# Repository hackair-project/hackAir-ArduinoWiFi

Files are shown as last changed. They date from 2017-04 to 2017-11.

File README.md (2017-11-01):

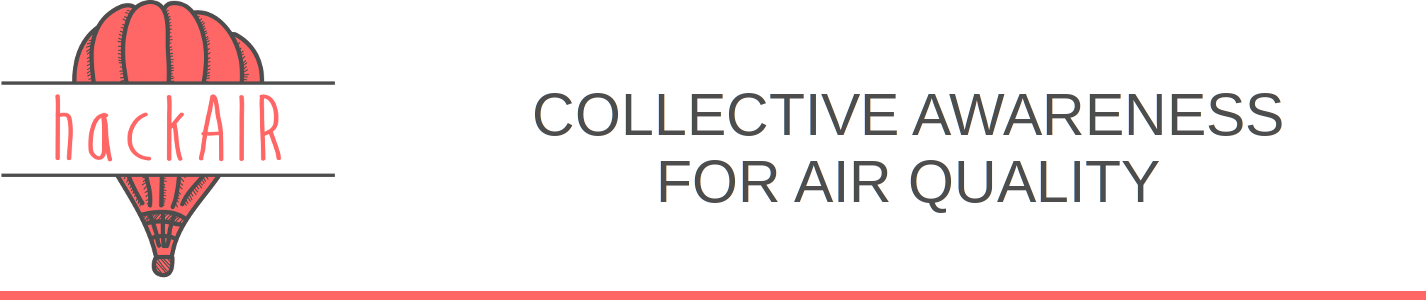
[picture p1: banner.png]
hackAIR banner with logo


hackAIR is an EU-funded project aiming to develop an open technology platform for citizen observatories on air quality. Air pollution is an environmental issue with serious health and lifespan implications. However, it remains difficult for citizens to assess their exposure to air pollution and air quality issues in their country. Official air quality sensors are often few and far between, coverage is poor outside cities, and their data is not always easily accessible.

## hackAIR WiFi shield

The hackAIR WiFi shield is a do-it-yourself solution for adding wireless connectivity to an Arduino node on the cheap. It's based around a custom PCB and the ESP8266 WiFi module and it's supported by the hackAIR firmware. All the network-related work is done by the WiFi module that can be controlled by simple serial commands. The [hackAIR library for Arduino](https://github.com/hackair-project/hackAir-Arduino) contains helpful wrapper functions to make using the shield easy and simple.

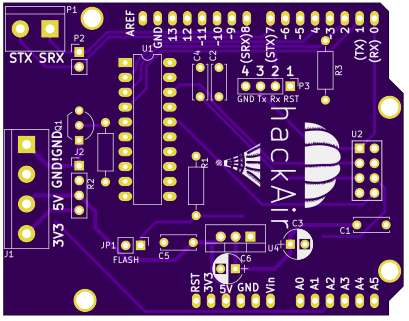
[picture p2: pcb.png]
PCB render


### Where to order

PCBs can be ordered directly from OSHPark [here](https://oshpark.com/shared_projects/u7Z6d8GR). The source files are included in this repository so anyone can order from their manufacturer of choice. Work is being done  to make complete kits available soon.

### Documentation

Documentation for this shield is under construction [here](https://hackair-project.github.io/hackAir-Arduino/wifi/).

### Technicalities

The PCB is designed using the open source EDA called [KiCad](http://kicad-pcb.org/). The PCB render shown above is created using [PcbDraw](https://github.com/yaqwsx/PcbDraw).

### Changelog

#### Version 2.2

* Fix silkscreen of transistor Q1
* Remove footprint for ESP-12
* Add silkscreen for the programming header (pin numbers and names)

#### Version 2
 - [Add] Pull-down resistor for pin 2 (ESP Reset) so the user can flash the Arduino without jumpers
 - [Add] Silkscreen markings for pin numbers
 - [Add] Programming header for the WiFi module
 - [Del] Removed sensor I/O header used by analog sensors
 - [Del] Removed the RC filter required by some analog sensors by SHARP
 - [Fix] Move some decoupling capacitors closer to the power pads
 - [Fix] Moved the CONN_POWER and CONN_SERIAL connectors away from the USB connector of the Arduino board
 - [Fix] Fixed some acid traps in the routing
 - [Fix] Fixed the footprint of Q1 (DSG -> DGS)
 - [Fix] Changed the foorprints of all non-electrolytic caps to be wider.
 - [Fix] Fixed the silkscreen of U1 appearing on the wrong layer.

#### Version 1
Initial release

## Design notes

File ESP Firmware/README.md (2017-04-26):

# ESP Firmware for the Arduino WiFi Shield
This directory houses the ESP firmware's source code along with the configuration landing page.

## Description & Features
The ESP microcontroller is responsible for the following things when using the hackAIR Arduino WiFi shield:

* Manage network connections
* Store AP keys
* Send data received from the Arduino to the hackAIR servers
* Handle WiFi configuration

To handle the WiFi pairing we are using nodemcu's internal 'End-User setup'. The end result can be achieved with
very little code and the page is customizable.

When it's powered on, the ESP checks if there are any known WiFi Access Points in range to connect. If nothing is
available, the ESP will start broadcasting it's own SSID and accept connections from other devices. The user can use
their phone to select a WiFi network for the Arduino to use and input it's password. When instructed by the Arduino, the
ESP will use this WiFi network to transmit gathered data.
 
List of features:
* Full featured HTTP server in AP mode.
* Easy-to-use landing page for configuring WiFi connections
* Handle all network stack duties, leaving the Arduino free to interface with external devices.
* Power saving mode for extending battery life (WIP)

## Install/Use
For users looking to install the firmware to their devices there are tutorials and pre-built images available.
For developers looking to modify the firmware, the development stack is based on Node.JS and the node package manager
(npm). From a terminal at this directory type:

    npm install
    
All required packages for developing will be installed. nodemcu-tool is used to manage writing files to the module.
A couple of npm scripts are available to aid in development:
 * `npm run upload`: Upload everything to the ESP module.
 * `npm run format`: Format the ESP's filesystem.
 * `npm run terminal`: Open a terminal to the ESP module.
 * `npm run build-image`: This will create a `app.bin` file that you can flash using `esptool.py`. This is useful when
 you want to flash both nodemcu and the init.lua in one step. 
 
If uploading is unstable you can try lowering the baud rate at `.nodemcutool`. 9600 is usually a safe bet but it's really slow.
 
## License

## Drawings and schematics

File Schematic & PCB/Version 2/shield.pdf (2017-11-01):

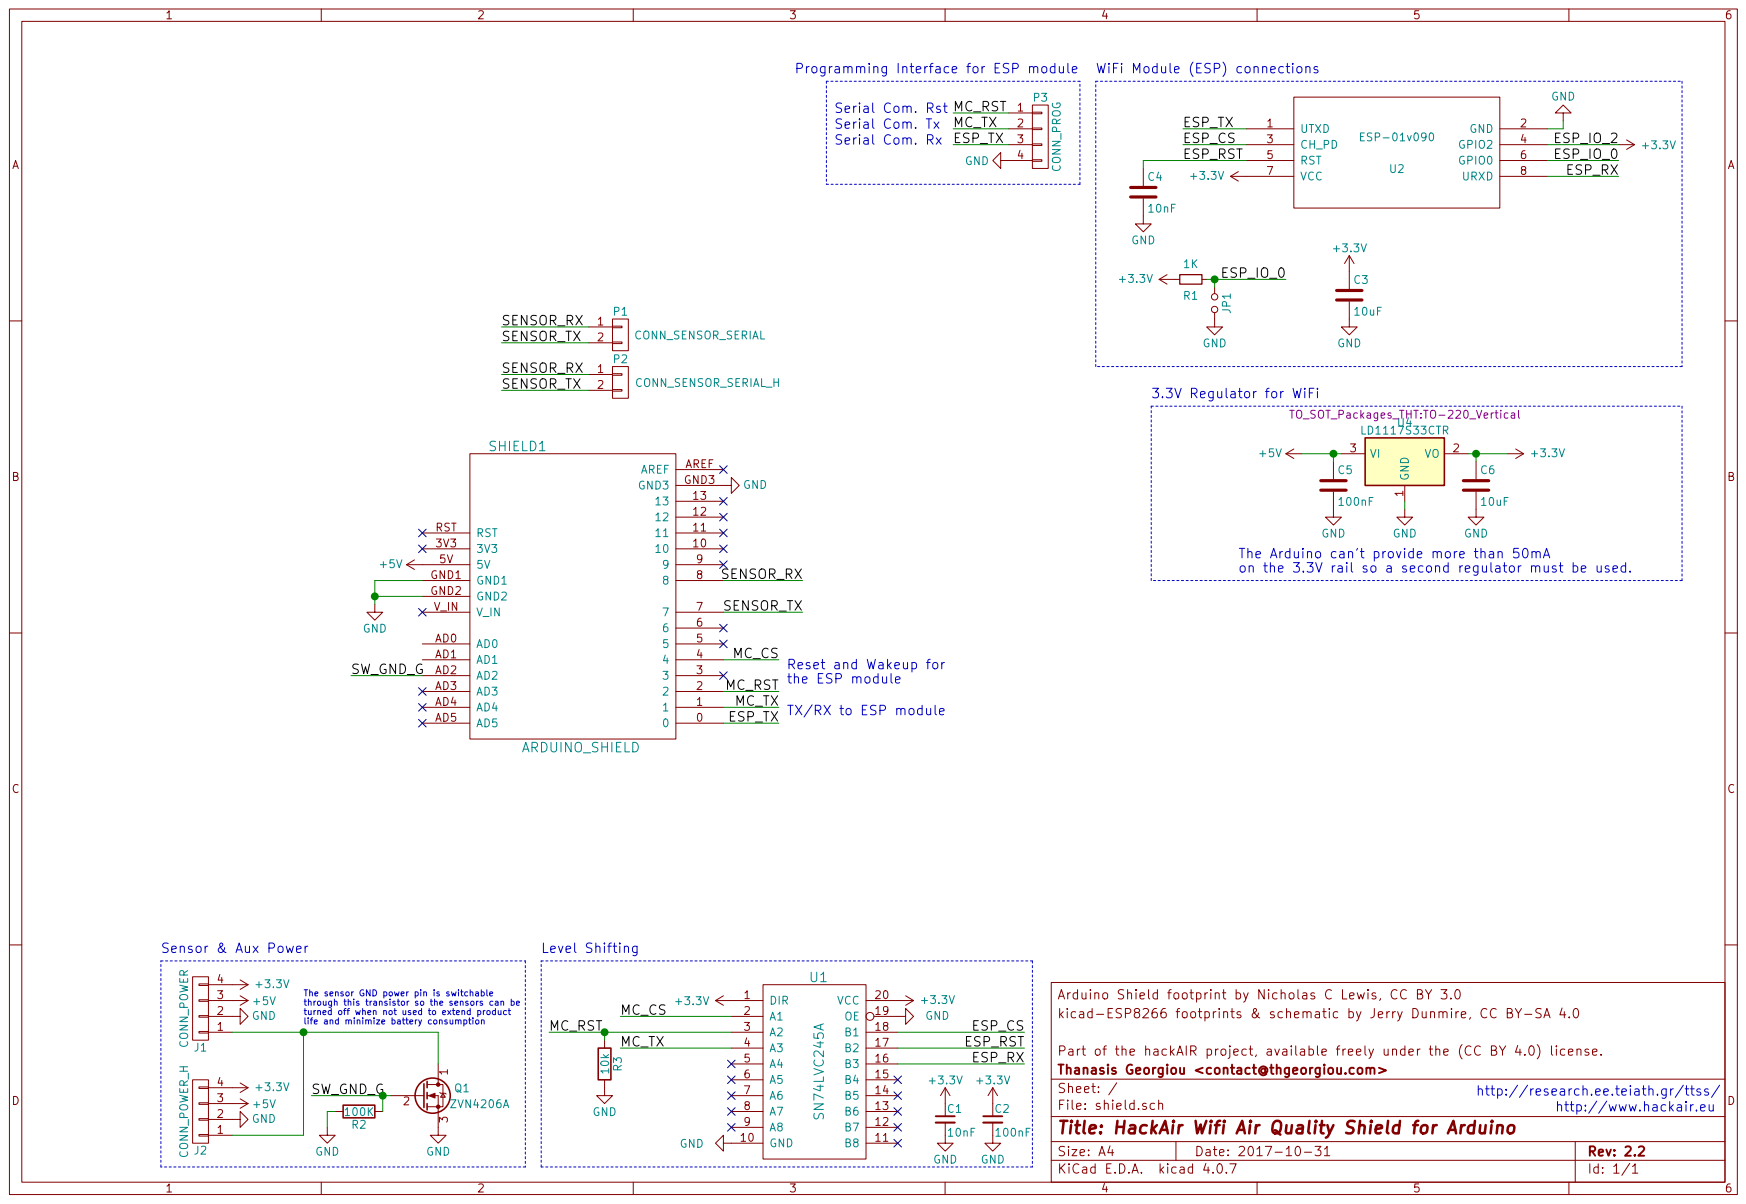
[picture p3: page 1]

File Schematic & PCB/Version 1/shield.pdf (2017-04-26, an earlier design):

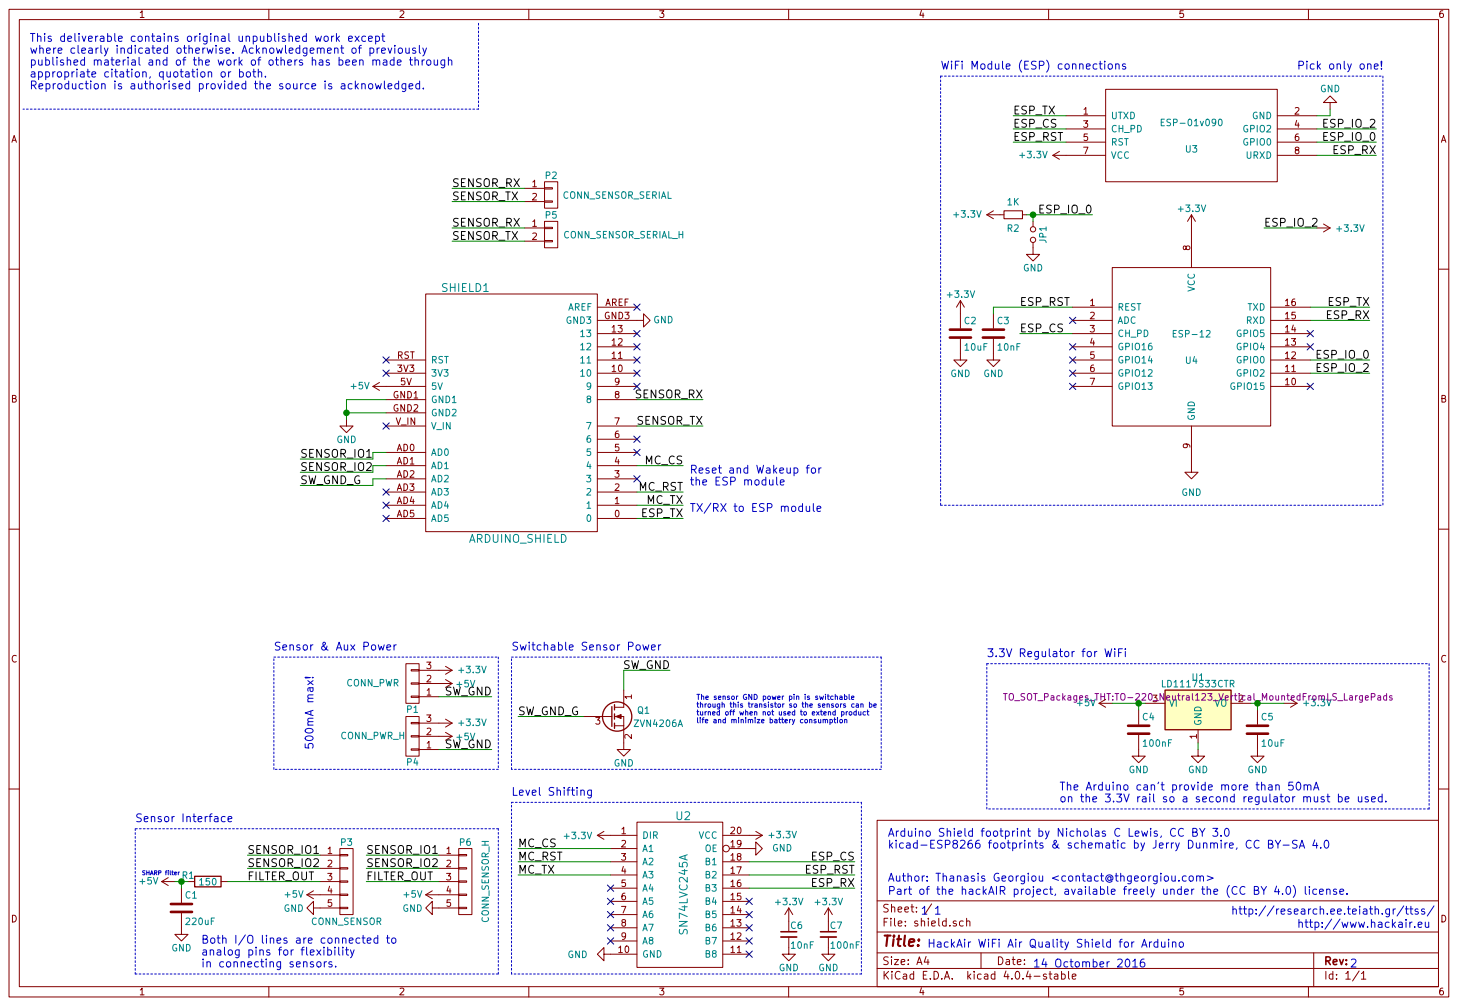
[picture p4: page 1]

where clearly indicated otherwise. Acknowledgement of previously
published material and of the work of others has been made through
appropriate citation, quotation or both.
Reproduction is authorised provided the source is acknowledged.

MC_CS Reset and Wakeup for

The sensor GND power pin is switchable
through this transistor so the sensors can be
turned off when not used to extend product

+5V The Arduino can't provide more than 50mA

kicad-ESP8266 footprints & schematic by Jerry Dunmire, CC BY-SA 4.0 1

Author: Thanasis Georgiou <contact@thgeorgiou.com>
Part of the hackAIR project, available freely under the (CC BY 4.0) license.
Id: 1/1 Title: File: shield.sch Sheet: /

220uF GND
Both I/O lines are connected to
analog pins for flexibility
in connecting sensors.

http://research.ee.teiath.gr/ttss/

http://www.hackair.eu

HackAir WiFi Air Quality Shield for Arduino

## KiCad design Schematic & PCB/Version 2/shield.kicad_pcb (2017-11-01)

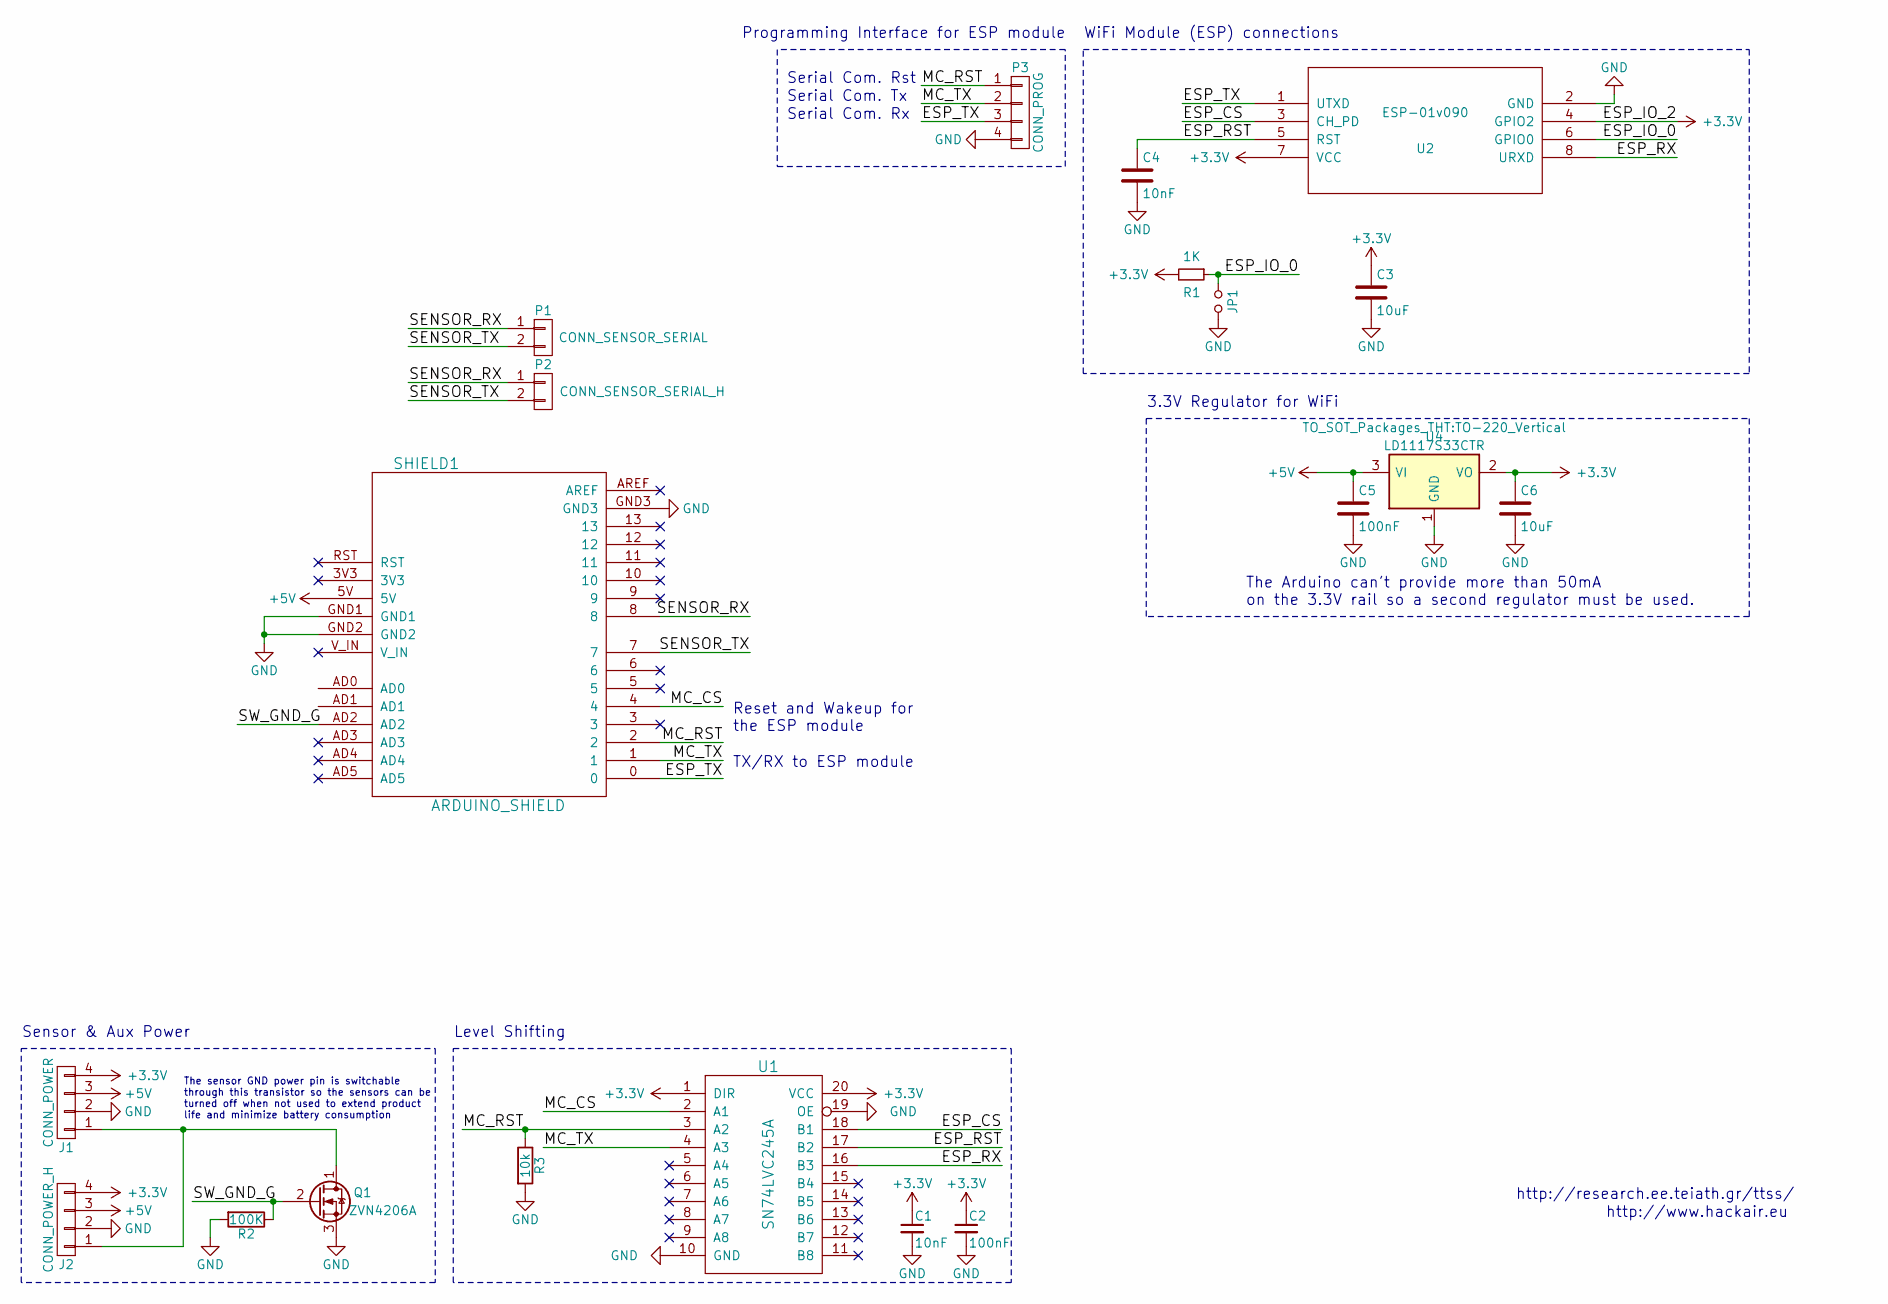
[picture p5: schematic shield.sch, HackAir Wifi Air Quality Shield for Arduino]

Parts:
C1, C4: 10nF; C_Disc_D6.0mm_W2.5mm_P5.00mm
C2, C5: 100nF; C_Disc_D6.0mm_W2.5mm_P5.00mm
C3, C6: 10uF; CP_Radial_D5.0mm_P2.50mm
J1: CONN_POWER; bornier4
J2: CONN_POWER_H; Pin_Header_Straight_1x04_Pitch2.54mm
JP1: Jumper_NO_Small; Pin_Header_Straight_1x02_Pitch2.54mm
P1: CONN_SENSOR_SERIAL; bornier2
P2: CONN_SENSOR_SERIAL_H; Pin_Header_Straight_1x02_Pitch2.54mm
P3: CONN_PROG; Pin_Header_Straight_1x04_Pitch2.54mm
Q1: ZVN4206A; TO-92_Inline_Wide
R1: 1K; R_Axial_DIN0207_L6.3mm_D2.5mm_P10.16mm_Horizontal
R2: 100K; R_Axial_DIN0207_L6.3mm_D2.5mm_P10.16mm_Horizontal
R3: 10k; R_Axial_DIN0207_L6.3mm_D2.5mm_P10.16mm_Horizontal
SHIELD1: ARDUINO_SHIELD; ARDUINO_SHIELD_2_040pins
U1: SN74LVC245A; DIP-20_W7.62mm_LongPads
U2: ESP-01v090; ESP-01
U4: LD1117S33CTR; TO-220_Vertical

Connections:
+3V3: C1.1, C2.1, C3.1, C6.1, J1.4, J2.4, R1.2, U1.1 (DIR), U1.20 (VCC), U2.4 (GPIO2), U2.7 (VCC), U4.2 (VO)
+5V: C5.1, J1.3, J2.3, SHIELD1.5V, U4.3 (VI)
/ESP_CS: U1.18 (B1), U2.3 (CH_PD)
/ESP_IO_0: JP1.1, R1.1, U2.6 (GPIO0)
/ESP_RST: C4.1, U1.17 (B2), U2.5 (RST)
/ESP_RX: U1.16 (B3), U2.8 (URXD)
/ESP_TX: P3.3, SHIELD1.0, U2.1 (UTXD)
/MC_CS: SHIELD1.4, U1.2 (A1)
/MC_RST: P3.1, R3.1, SHIELD1.2, U1.3 (A2)
/MC_TX: P3.2, SHIELD1.1, U1.4 (A3)
/SENSOR_RX: P1.1, P2.1, SHIELD1.8
/SENSOR_TX: P1.2, P2.2, SHIELD1.7
/SW_GND_G: Q1.2 (G), R2.1, SHIELD1.AD2
GND: C1.2, C2.2, C3.2, C4.2, C5.2, C6.2, J1.2, J2.2, JP1.2, P3.4, Q1.3 (S), R2.2, R3.2, SHIELD1.GND1, SHIELD1.GND2, SHIELD1.GND3, U1.10 (GND), U1.19 (OE), U2.2 (GND), U4.1 (GND)
unnamed: J1.1, J2.1, Q1.1 (D)

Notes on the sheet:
The Arduino can't provide more than 50mA on the 3.3V rail so a second regulator must be used.
TX/RX to ESP module
Reset and Wakeup for the ESP module
WiFi Module (ESP) connections
3.3V Regulator for WiFi
Level Shifting
http://research.ee.teiath.gr/ttss/
http://www.hackair.eu
The sensor GND power pin is switchable through this transistor so the sensors can be turned off when not used to extend product life and minimize battery consumption
Sensor & Aux Power
Serial Com. Tx
Serial Com. Rx
Serial Com. Rst
Programming Interface for ESP module

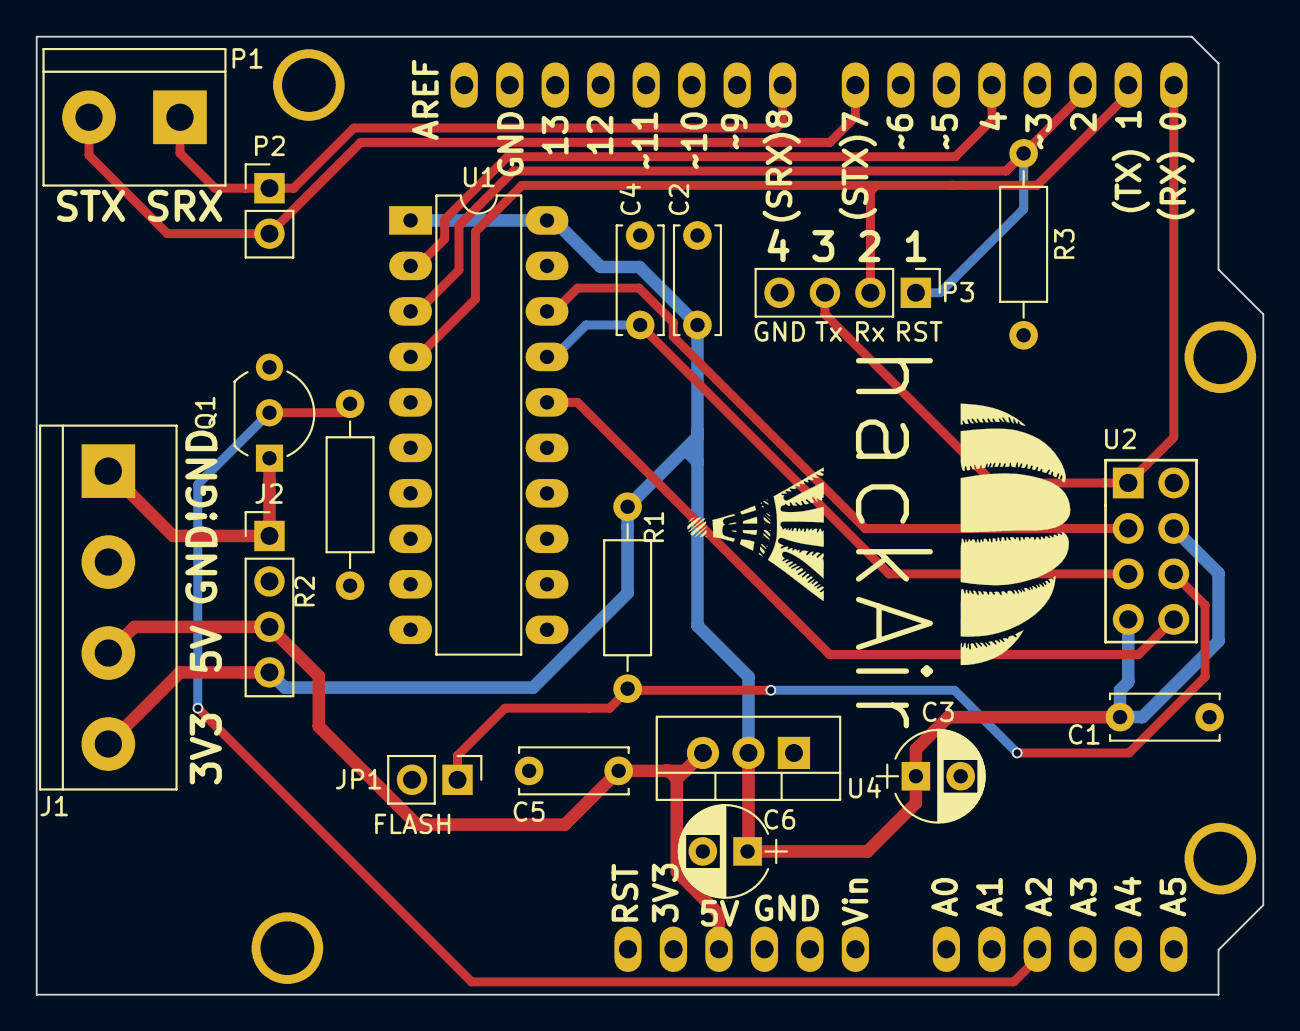
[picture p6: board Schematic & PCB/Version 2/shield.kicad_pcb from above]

Board: 2 copper layers, 68.5 x 53.5 mm, 20 parts (0 on the bottom side), 15 nets.

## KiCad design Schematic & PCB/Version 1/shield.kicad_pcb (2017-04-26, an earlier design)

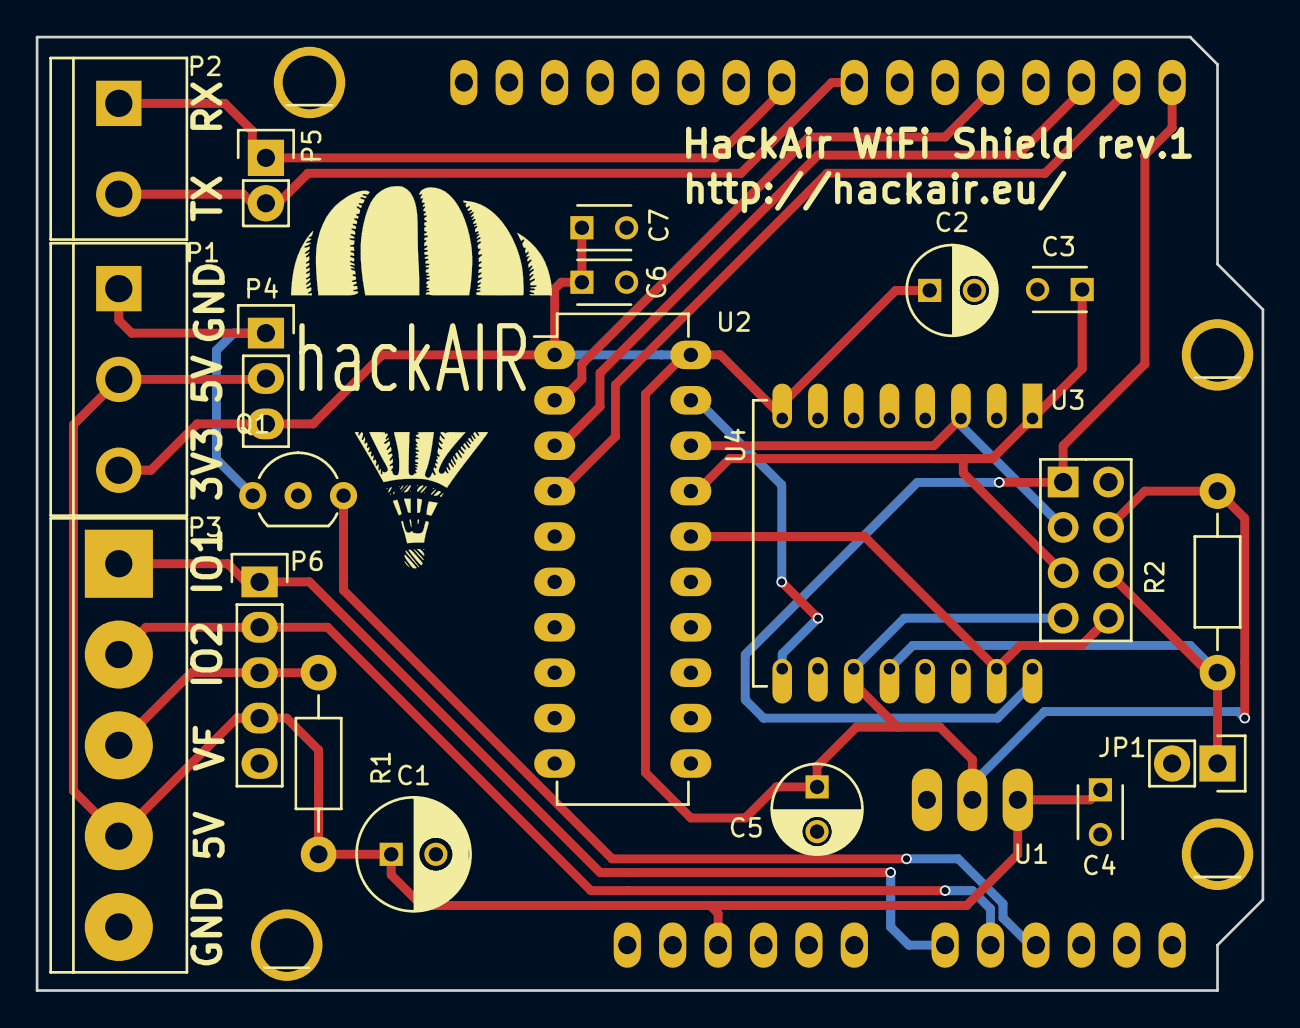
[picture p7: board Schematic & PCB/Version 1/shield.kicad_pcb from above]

Board: 2 copper layers, 68.6 x 53.3 mm, 26 parts (1 on the bottom side), 18 nets.

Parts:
C1: 220uF; C_Radial_D6.3_L11.2_P2.5
C2, C5: 10uF; C_Radial_D5_L11_P2.5
C3, C6: 10nF; C_Disc_D3_P2.5
C4, C7: 100nF; C_Disc_D3_P2.5
HOLE: Pin_Header_Straight_1x01
HOLE#2, HOLE#3, HOLE#4: Pin_Header_Straight_1x01
JP1: Jumper_NO_Small; Pin_Header_Straight_1x02
P1: CONN_PWR; bornier3
P2: CONN_SENSOR_SERIAL; bornier2
P3: CONN_SENSOR; bornier5
P4: CONN_PWR_H; Pin_Header_Straight_1x03
P5: CONN_SENSOR_SERIAL_H; Pin_Header_Straight_1x02
P6: CONN_SENSOR_H; Pin_Header_Straight_1x05
Q1: ZVN4206A; TO-92_Inline_Wide
R1: 150; Resistor_Horizontal_RM10mm
R2: 1K; Resistor_Horizontal_RM10mm
SHIELD1: ARDUINO_SHIELD; ARDUINO_SHIELD_2_040pins
U1: LD1117S33CTR; TO-220_Neutral123_Vertical_MountedFromLS_LargePads
U2: SN74LVC245A; DIP-20_W7.62mm_LongPads
U3: ESP-01v090; ESP-01
U4: ESP-12

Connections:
+3V3: C2.1, C5.1, C6.1, C7.1, P1.3, P4.3, R2.2, U1.2, U2.1, U2.20, U3.4, U3.7, U4.8, U4.11
+5V: C1.1, C4.1, P1.2, P3.4, P4.2, P6.4, R1.2, SHIELD1.5V, U1.3
/ESP_CS: U2.18, U3.3, U4.3
/ESP_IO_0: JP1.1, R2.1, U3.6, U4.12
/ESP_RST: C3.1, U2.17, U3.5, U4.1
/ESP_RX: U2.16, U3.8, U4.15
/ESP_TX: SHIELD1.0, U3.1, U4.16
/FILTER_OUT: P3.3, P6.3, R1.1
/MC_CS: SHIELD1.4, U2.2
/MC_RST: SHIELD1.2, U2.3
/MC_TX: SHIELD1.1, U2.4
/SENSOR_IO1: P3.1, P6.1, SHIELD1.AD0
/SENSOR_IO2: P3.2, P6.2, SHIELD1.AD1
/SENSOR_RX: P2.1, P5.1, SHIELD1.8
/SENSOR_TX: P2.2, P5.2, SHIELD1.7
/SW_GND: P1.1, P4.1, Q1.1
/SW_GND_G: Q1.3, SHIELD1.AD2
GND: C1.2, C2.2, C3.2, C4.2, C5.2, C6.2, C7.2, JP1.2, P3.5, P6.5, Q1.2, SHIELD1.GND1, SHIELD1.GND2, SHIELD1.GND3, U1.1, U2.10, U2.19, U3.2, U4.9

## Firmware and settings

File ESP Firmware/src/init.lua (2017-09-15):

--- hackAIR ESP Firmware
-- Handles WiFi setup and network communications
-- @version 0.5.0
-- @author Thanasis Georgiou

--- The server URL used for sending data to the hackAIR project
server_URL = "https://api.hackair.eu/sensors/arduino/measurements"
auth_token = ""

function sent_data(args)
    -- Prepare HTTP headers
    local headers = 'Content-Type: application/json\r\n' ..
                    'HTTP Accept header: application/vnd.hackair.v1+json\r\n' ..
                    'Authorization: ' .. auth_token .. '\r\n'

    -- Parse arguments from serial and encode them in JSON
    local pm25, pm10, battery, tamper, err =
        string.match(args, "([^,]+),([^,]+),([^,]+),([^,]+),([^,]*)")

    local body = string.format([[{
        "reading": {
            "PM2.5_AirPollutantValue":"%s",
            "PM10_AirPollutantValue":"%s"
        },
        "battery":"%s",
        "tamper":"%s",
        "error":"%s"
    }]], pm25, pm10, battery, tamper, err)

    -- Make the request
    --noinspection UnusedDef
    http.post(server_URL, headers, body,
        function(code, data)
            uart.write(0, tostring(code))
        end
    )
end

--- Handle UART commands
-- The first word (string until first space) is the command, the rest is
-- parameters. Each command is terminated with a \n.
-- @param UART input, must be parsed
function handle_uart(data)
    -- Parse parameters
    local com, args = string.match(data, "([^%s]+)%s([^%s]+)")
    if com == nil then
        com = string.sub(data, 1, -2)
    end

    -- Execute commands
    if com == 'e+raw' then -- Enter raw mode (lua console)
        uart.on("data")
        uart.setup(0, 115200, 8, uart.PARITY_NONE, uart.STOPBITS_1, 1)
        print('Lua Shell mode')
    elseif com == 'e+restart' then -- Restart ESP
        node.restart()
    elseif com == 'e+version' then -- Version info
        uart.write(0, 'v5')
    elseif com == 'e+send' then -- Send data to server
        if args == nil then
            print('Command e+send requires parameters (pm25, pm10, battery, tamper, error)')
        else
            sent_data(args)
        end
    elseif com == 'e+clearap' then -- Clear saved access points
        wifi.sta.clearconfig()
        node.restart()
    elseif com == 'e+token' then -- Grab the token for authorization
        if args == nil then
            print('Command e+token required parameters (token)')
        else
            auth_token = args
        end
    elseif com == 'e+wifi' then -- Set the SSID to connect to
        if args == nil then
            print('Command e+wifi requires two parameters, SSID and password')
            print('SSIDs and passwords with commas "," are not supported, please use the WiFi method')
        else
            local ssid, password = string.match(args, "([^,]+),([^,]*)")
            if ssid ~= nil and password ~= nil then
                wifi.sta.config({ssid = ssid, pwd = password, auto = true})
                enduser_setup.stop()
            else
                print('Invalid parameters')
            end
        end
    elseif com == 'e+isready' then -- Is the ESP ready and connected?
        if wifi.sta.getip() ~= nil then
            uart.write(0, tostring(1))
        else
            uart.write(0, tostring(0))
        end
    else
        print('Unknown command ' .. com)
    end
end

-- Start listening to UART for commands
uart.setup(0, 115200, 8, uart.PARITY_NONE, uart.STOPBITS_1, 0)
uart.on('data', "\n", handle_uart, 0)

ssid, password, bssid_set, bssid = wifi.sta.getconfig()
if ssid == '' then
    print('No WiFi configuration stored, going into AP mode')
    enduser_setup.start(
      function()
          -- Print debug info
          ssid, password, bssid_set, bssid = wifi.sta.getconfig()
          print('Connected to '.. ssid .. ' with password ' .. password .. ' as: ' .. wifi.sta.getip())
      end,
      function(err, str)
          print('enduser_setup: Err #' .. err .. ': ' .. str)
      end
    )
else
    wifi.setmode(wifi.STATION)
    wifi.sta.connect()
end

-- Display a warning message to the prompt
print('hackAir ESP Firmware')
print('Entering serial command mode, to use the Lua terminal send "e+raw"')

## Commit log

2017-07-07 Switch enduser_setup to manual mode so we can have our custom SSID
2017-07-09 Switch enduser_setup back to automatic mode since manual was unstable
    [init.lua]
2017-09-29 Add PCBDraw SVG drawing of the PCB
2017-11-01 Shield design revision (v2.2)
    [shield.kicad_pcb, shield.sch]

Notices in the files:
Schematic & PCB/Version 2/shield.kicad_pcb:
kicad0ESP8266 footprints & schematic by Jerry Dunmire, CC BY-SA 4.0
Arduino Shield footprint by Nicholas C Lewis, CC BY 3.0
